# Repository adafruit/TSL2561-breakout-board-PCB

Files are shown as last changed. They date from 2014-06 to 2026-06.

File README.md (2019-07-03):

## TSL2561 breakout board PCB

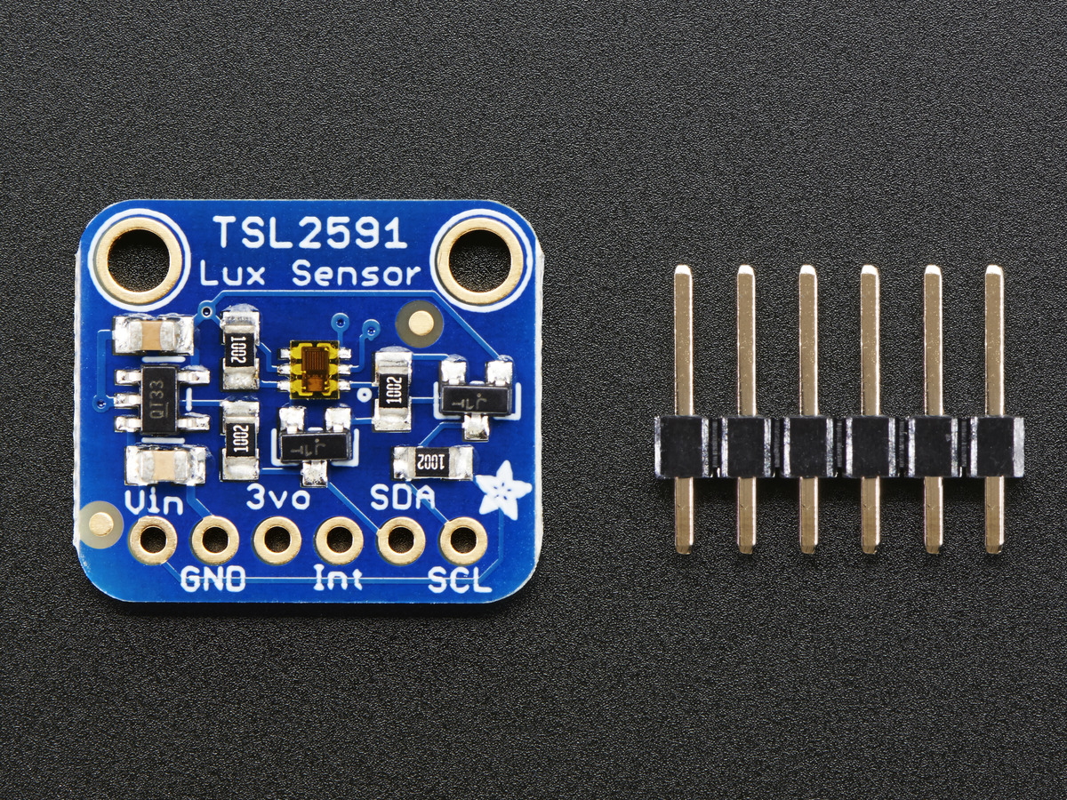
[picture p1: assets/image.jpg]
<a href="http://www.adafruit.com/products/1980"><br/>
Click picture or link below to purchase one from the Adafruit shop</a>

PCB CAD files for the Adafruit TSL2591 High Dynamic Range Digital Light Sensor. 
PCB format is EagleCAD schematic and board layout

For more details, check out the product page at
* https://www.adafruit.com/products/1980

### Description

When the future is dazzlingly-bright, this ultra-high-range luminosity sensor will help you measure it. The TSL2591 luminosity sensor is an advanced digital light sensor, ideal for use in a wide range of light situations. Compared to low cost CdS cells, this sensor is more precise, allowing for exact lux calculations and can be configured for different gain/timing ranges to detect light ranges from 188 uLux up to 88,000 Lux on the fly.

The best part of this sensor is that it contains both infrared and full spectrum diodes! That means you can separately measure infrared, full-spectrum or human-visible light. Most sensors can only detect one or the other, which does not accurately represent what human eyes see (since we cannot perceive the IR light that is detected by most photo diodes) This sensor is much like the TSL2561 but with a wider range (and the interface code is different). This sensor has a massive 600,000,000:1 dynamic range! Unlike the TSL2561 you cannot change the I2C address, so keep that in mind.

The built in ADC means you can use this with any microcontroller, even if it doesn't have analog inputs. The current draw is extremely low, so its great for low power data-logging systems. about 0.4mA when actively sensing, and less than 5 uA when in power-down mode.

### License

Adafruit invests time and resources providing this open source design, please support Adafruit and open-source hardware by purchasing products from [Adafruit](https://www.adafruit.com)!

Designed by Limor Fried/Ladyada for Adafruit Industries.

Creative Commons Attribution/Share-Alike, all text above must be included in any redistribution. See license.txt for additional details.

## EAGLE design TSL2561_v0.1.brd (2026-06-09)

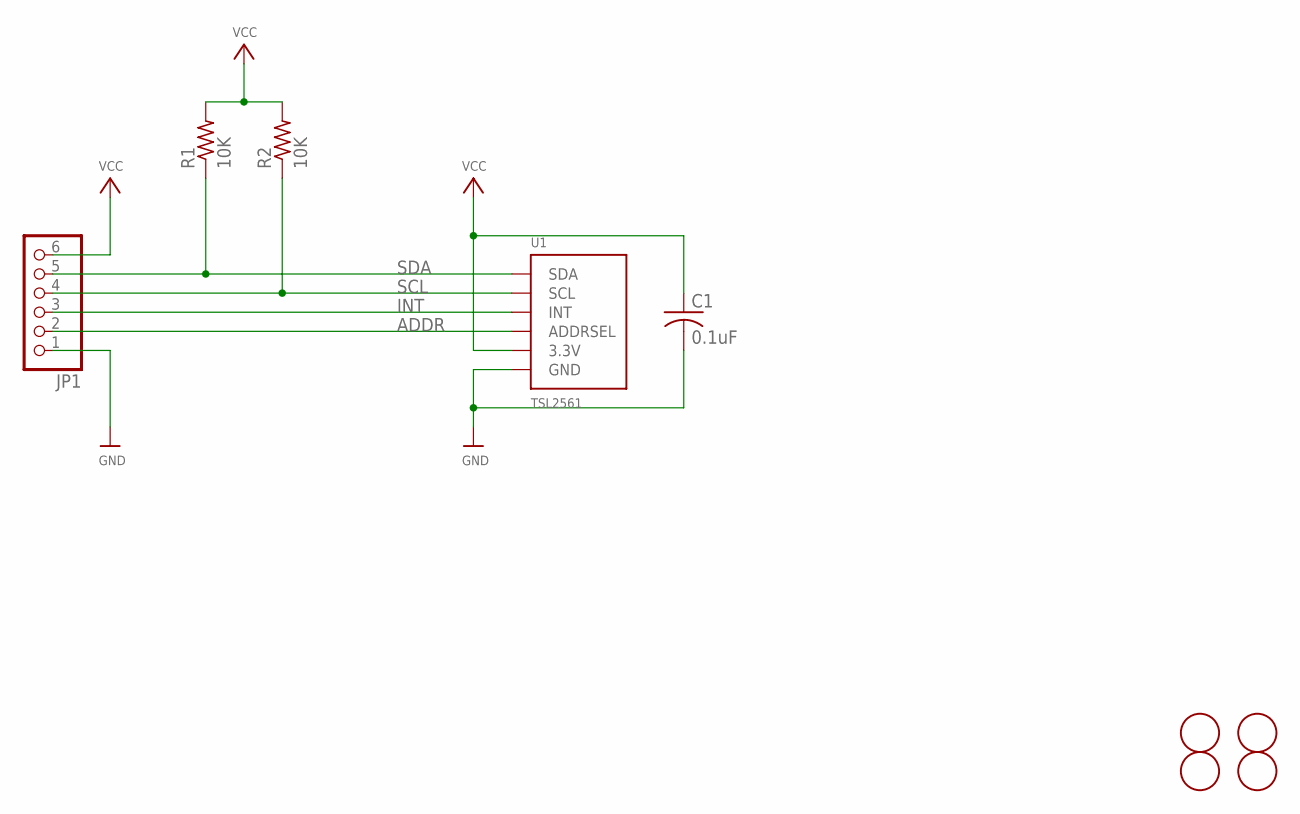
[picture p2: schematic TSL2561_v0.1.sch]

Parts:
C1: 0.1uF; C0805
JP1: HEADER-1X676MIL; 1X06_ROUND_76
R1, R2: 10K; R0805
U1: TSL2561; TSL2561_FN
U$2, U$4: FIDUCIAL; FIDUCIAL_1MM
U$5, U$6: MOUNTINGHOLE2.0; MOUNTINGHOLE_2.0_PLATED

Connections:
ADDR: JP1.2, U1.ADR (ADDRSEL)
GND: C1.2, JP1.1, U1.VSS (GND)
INT: JP1.3, U1.INT
SCL: JP1.4, R2.1, U1.CLK (SCL)
SDA: JP1.5, R1.1, U1.DATA (SDA)
VCC: C1.1, JP1.6, R1.2, R2.2, U1.VDD (3.3V)

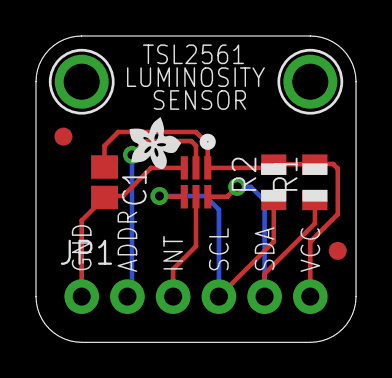
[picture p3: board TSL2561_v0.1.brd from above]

Board: 2 copper layers, 17.8 x 17.0 mm, 10 parts (0 on the bottom side), 6 nets.

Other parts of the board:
U$7: ADAFRUIT200MIL

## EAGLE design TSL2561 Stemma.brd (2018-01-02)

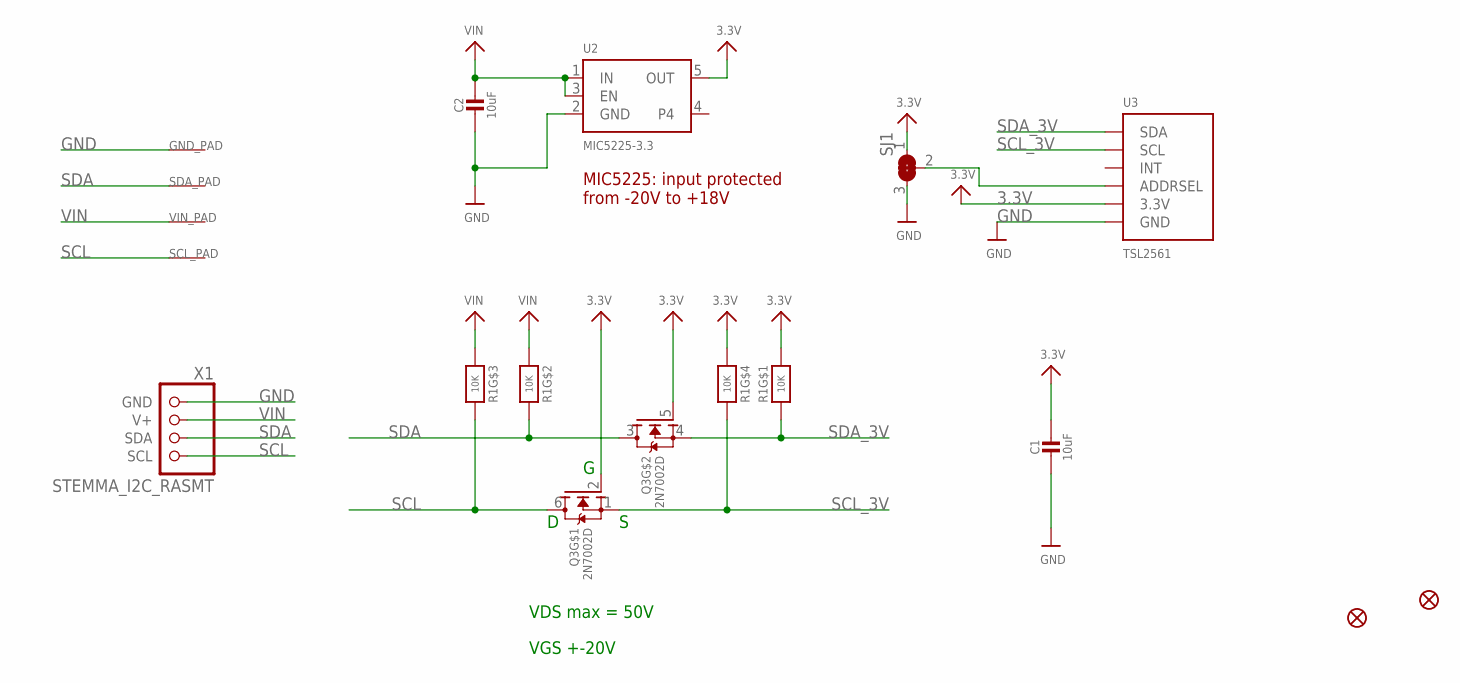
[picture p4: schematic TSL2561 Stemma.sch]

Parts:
C1, C2: 10uF; 0805-NO
FID1, FID2: FIDUCIAL_1MM
GND_PAD: SEWTAP-ALLIGATOR; SEWALLI
Q3: 2N7002D; SOT363
R1: 10K; RESPACK_4X0603
SCL_PAD: SEWTAP-ALLIGATOR; SEWALLI
SDA_PAD: SEWTAP-ALLIGATOR; SEWALLI
SJ1: SOLDERJUMPER_2WAY; SOLDERJUMPER_2WAY_OPEN_NOPASTE
U2: MIC5225-3.3; SOT23-5
U3: TSL2561; TSL2561_FN
VIN_PAD: SEWTAP-ALLIGATOR; SEWALLI
X1: STEMMA_I2C_RASMT; JSTPH4

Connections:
3.3V: C1.1, Q3.2 (G), Q3.5 (G), R1.1, R1.5 (2), SJ1.1, U2.5 (OUT), U3.VDD (3.3V)
GND: C1.2, C2.2, GND_PAD.P$1, SJ1.3, U2.2 (GND), U3.VSS (GND), X1.1 (GND)
unnamed: SJ1.2, U3.ADR (ADDRSEL)
SCL: Q3.6 (D), R1.6 (2), SCL_PAD.P$1, X1.4 (SCL)
SCL_3V: Q3.1 (S), R1.4 (1), U3.CLK (SCL)
SDA: Q3.3 (D), R1.7 (2), SDA_PAD.P$1, X1.3 (SDA)
SDA_3V: Q3.4 (S), R1.8 (2), U3.DATA (SDA)
VIN: C2.1, R1.2 (1), R1.3 (1), U2.1 (IN), U2.3 (EN), VIN_PAD.P$1, X1.2 (V+)

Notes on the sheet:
MIC5225: input protected from -20V to +18V
VDS max = 50V
VGS +-20V

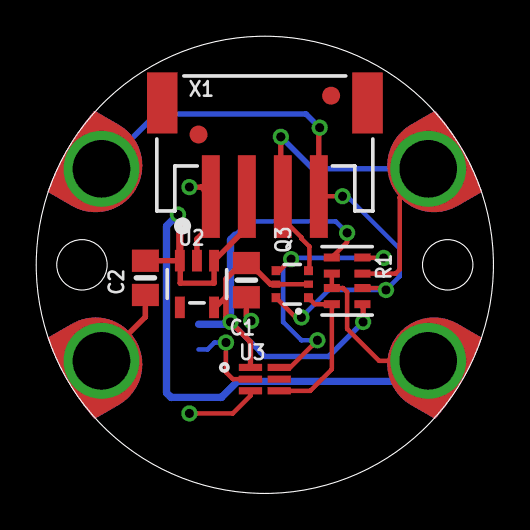
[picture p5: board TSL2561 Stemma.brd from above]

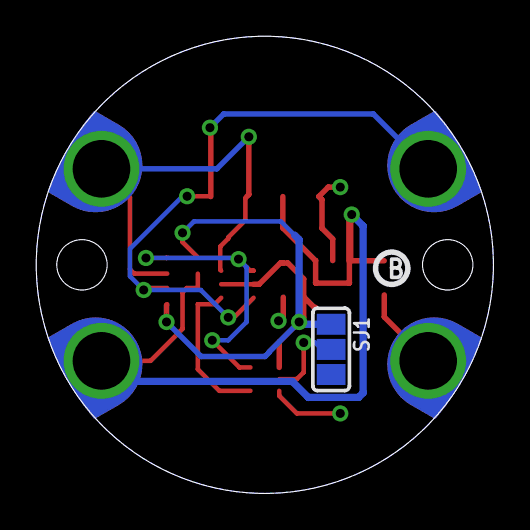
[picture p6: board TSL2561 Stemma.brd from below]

Board: 2 copper layers, 25.4 x 25.4 mm, 17 parts (3 on the bottom side), 8 nets.

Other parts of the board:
U$4: STEMMA_TSL2561_B_FRONT
U$7: STEMMA_TSL2561_B_BACK
U$8: PCBFEAT-REV-040

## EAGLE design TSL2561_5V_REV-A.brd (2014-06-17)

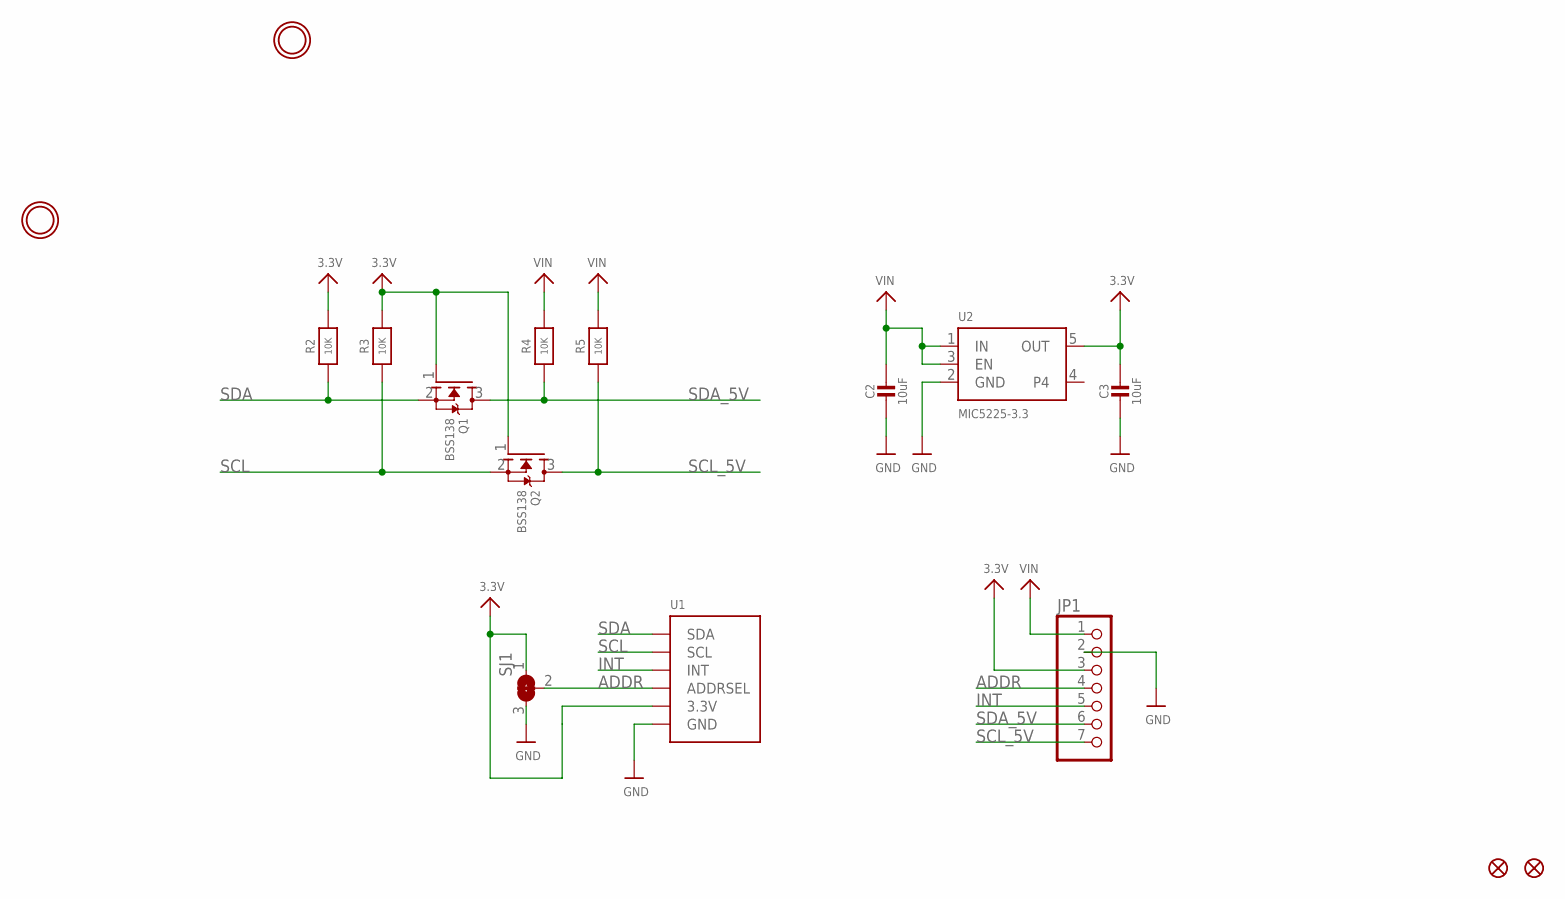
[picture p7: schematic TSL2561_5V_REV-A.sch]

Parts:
C2, C3: 10uF; 0805-NO
FID1, FID2: FIDUCIAL""; FIDUCIAL_1MM
JP1: HEADER-1X7THICKER; 1X07_ROUND_76
Q1, Q2: BSS138; SOT23-WIDE
R2, R3, R4, R5: 10K; 0805-NO
SJ1: SOLDERJUMPER_2WAY; SOLDERJUMPER_2WAY_OPEN_NOPASTE
U1: LIGHT_TSL2561; TSL2561_FN
U2: MIC5225-3.3; SOT23-5
U$18, U$19: MOUNTINGHOLE2.5; MOUNTINGHOLE_2.5_PLATED

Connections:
3.3V: C3.1, JP1.3, Q1.1 (G), Q2.1 (G), R2.2, R3.2, SJ1.1, U1.VDD (3.3V), U2.5 (OUT)
ADDR: JP1.4, SJ1.2, U1.ADR (ADDRSEL)
GND: C2.2, C3.2, JP1.2, SJ1.3, U1.VSS (GND), U2.2 (GND)
INT: JP1.5, U1.INT
SCL: Q2.2 (S), R3.1, U1.CLK (SCL)
SCL_5V: JP1.7, Q2.3 (D), R5.1
SDA: Q1.2 (S), R2.1, U1.DATA (SDA)
SDA_5V: JP1.6, Q1.3 (D), R4.1
VIN: C2.1, JP1.1, R4.2, R5.2, U2.1 (IN), U2.3 (EN)

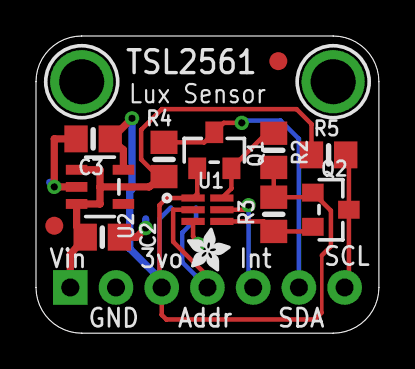
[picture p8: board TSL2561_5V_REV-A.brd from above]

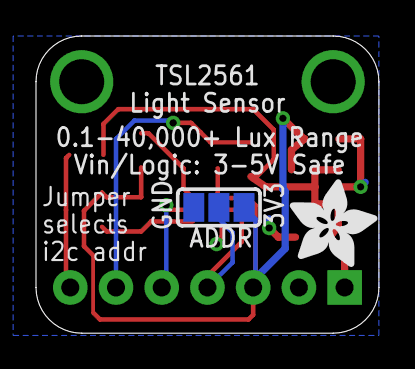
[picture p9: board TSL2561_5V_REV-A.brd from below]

Board: 2 copper layers, 19.1 x 16.5 mm, 18 parts (2 on the bottom side), 9 nets.

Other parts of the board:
U$15: ADAFRUIT_2.5MM
U$20: ADAFRUIT_5MM

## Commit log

2011-08-29 release layout files
    [TSL2561_v0.1.brd, TSL2561_v0.1.sch]
2014-06-17 5V version
    [TSL2561_5V_REV-A.brd, TSL2561_5V_REV-A.sch]
2018-01-02 stemma pcbs
    [TSL2561 Stemma.brd, TSL2561 Stemma.sch]
2026-06-03 update file format to XML
    [TSL2561_v0.1.brd, TSL2561_v0.1.sch]

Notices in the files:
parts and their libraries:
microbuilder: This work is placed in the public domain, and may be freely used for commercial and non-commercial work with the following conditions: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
